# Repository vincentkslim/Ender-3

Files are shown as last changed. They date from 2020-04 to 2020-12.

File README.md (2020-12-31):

# Ender i3 Pro

This reposity contains all of the modifications I have made to my Ender 3 Pro, which I now call the
Ender i3 Pro due to the heavy design inspiration of the Prusa i3 series on my [completely redesigned x-axis carraige](#x-carriage). 
This was forked from the official Creality Ender-3 repository, which does not include files for the 
Ender 3 Pro. However, the only files that are officially open sourced are for the Ender 3. The 
differences between the Ender 3 and Ender 3 Pro aren't that great, and so most of the mechanical 
upgrades that I have made are compatible with both the Ender 3 and the Ender 3 Pro, with few exceptions.

## Mechanical upgrades

The mechanical upgrades are in the [Ender-3 Mechanical/Ender-3 Upgrades/](Ender-3%20Mechanical/Ender-3%20Upgrades)
folder. Inside that folder are a series of other folders, each containing a different upgrade. I 
designed each of these upgrades using Solidworks 2019-2020.

Here is a description of each of the folders:

### [ABL](Ender-3%20Mechanical/Ender-3%20Upgrades/ABL)

This was an experimental upgrade that tried to add auto bed leveling using the z-axis microswitch
and an allen key that was attached to the x-axis carriage. In my testing, this did not work that 
well and was not accurate enough to produce usable measurements. 

### [Direct Drive](Ender-3%20Mechanical/Ender-3%20Upgrades/Direct%20Drive)

This simply repositioned the stock extruder system to be attached to the x-axis carriage. This was a
modification of (this adapter on thingiverse)[https://www.thingiverse.com/thing:3386628] that
was modified to fit the Hero Me cooling system. 

**DO NOT USE THIS OR THE HERO ME COOLING SYSTEM, ESPECIALLY IF YOU HAVE A V6 STYLE HOTEND**. 
If you look at the model, the heatsink fan duct does not direct air to the lowest fins on the hotend
heatsink, which is where cooling is needed **the most**. In my testing, I ran into tons of heat creep
issues when I used filament seceptible to heat creep such as Prusament PLA (Prusament PLA has been
extensively documented as seceptible to heat creep).

### [E3D V6](Ender-3%20Mechanical/Ender-3%20Upgrades/E3D%20V6)

This is simply a model of the E3D V6 hotend pulled from GrabCAD [here](https://grabcad.com/library/e3d-v6-hotend-3).
When you download it from GrabCAD, the mate (in Solidworks) between the heat break and the nozzle is incorrect, so 
the length of the entire hotend from the top of the heatsink to the tip of the nozzle is shorter than
it should be. After fixing that mate, the length of the entire hotend is correct. 

### [Radial Cooling Fan 50mm DC12V](Ender-3%20Mechanical/Ender-3%20Upgrades/Radial%20Cooling%20Fan%2050mm%20DC12V)

This is just a model of a generic 5015 blower fan.

### [Rear Electronics Case](Ender-3%20Mechanical/Ender-3%20Upgrades/Rear%20Electronics%20Case)

This is a rear electronics case meant to replace the sheet metal electronics enclosure of the stock
Ender 3 and Ender 3 Pro. On the Ender 3 Pro, the electronics enclosure is opened from the bottom, 
making it absurdly annoying to change any of the wiring (for example, replacing the mainboard). 
This rear electronics case was heavily inspired by 
[Teaching Tech's rear electronics case](https://www.thingiverse.com/thing:3688967) as well, but
I designed one myself just for design practice and because I wanted to make a few modifications, 
including:

* Cable chain clips that work with [this](https://www.thingiverse.com/thing:2920060) popular printable
cable chain for the Ender 3
* Fan that points directly at the mainboard
* Cable tie mounting points
* Buck converter mounting points, which enables the Ender 3 power supply to power a Raspberry Pi.

One known issue is that the tolerances are much too tight, which makes it hard to slide in the case
at the back. Will fix in a future revision.

### [Samla Box clips](Ender-3%20Mechanical/Ender-3%20Upgrades/Samla%20Box%20clips)

These are box clips for the [IKEA SAMLA series](https://www.ikea.com/us/en/cat/samla-series-12553/)
of storage boxes. I intended to use these to make a filament drybox, but I have not gotten around to
completing that project.

### [X Carriage](Ender-3%20Mechanical/Ender-3%20Upgrades/X%20Carriage)

This is my biggest and most important upgrade. This upgrade is complete and is currently in use on
the current iteration of my Ender 3 Pro. This is a completely redesigned x-axis carriage that scraps
all the stock hot-end parts except for the metal plate and the three rollers. Features include:

* Direct Drive
* E3D V6 support
* Can use 30mm hotend cooling fan and fan duct included with the V6
* Can use a 4010 (or 4020) hotend cooling fan with a fan duct adapter
* Custom extruder with Bondtech dual drive gear support
* 5015 part cooling fan and fan duct

My design takes heavy inspiration from the Prusa i3 x-axis carriage design. 

### [Raspberry Pi 3 Model B](Ender-3%20Mechanical/Ender-3%20Upgrades/raspberry-pi-3-model-b-reference-design-solidworks-cad-rpi-raspberrypi-raspberry-pi-1.snapshot.83)

This is just a model of the Raspberry Pi 3 Model B that I use to run Octoprint and Klipper.

## Software upgrades

The software modifications I made are not included in this directory. The main change I made was 
installing [Klipper](https://www.klipper3d.org/) instead of Marlin for the firmware and having it 
run via Octoprint. I use PrusaSlicer as my slicer, although I have had good experience with Ultimaker
Cura and would recommend that as well (I used that originally).

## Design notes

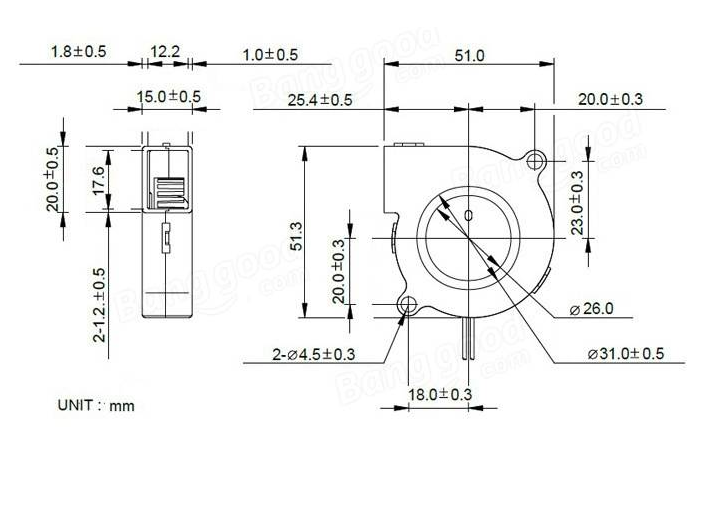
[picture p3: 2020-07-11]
Ender-3 Mechanical/Ender-3 Upgrades/Radial Cooling Fan 50mm DC12V/5015 fan.PNG

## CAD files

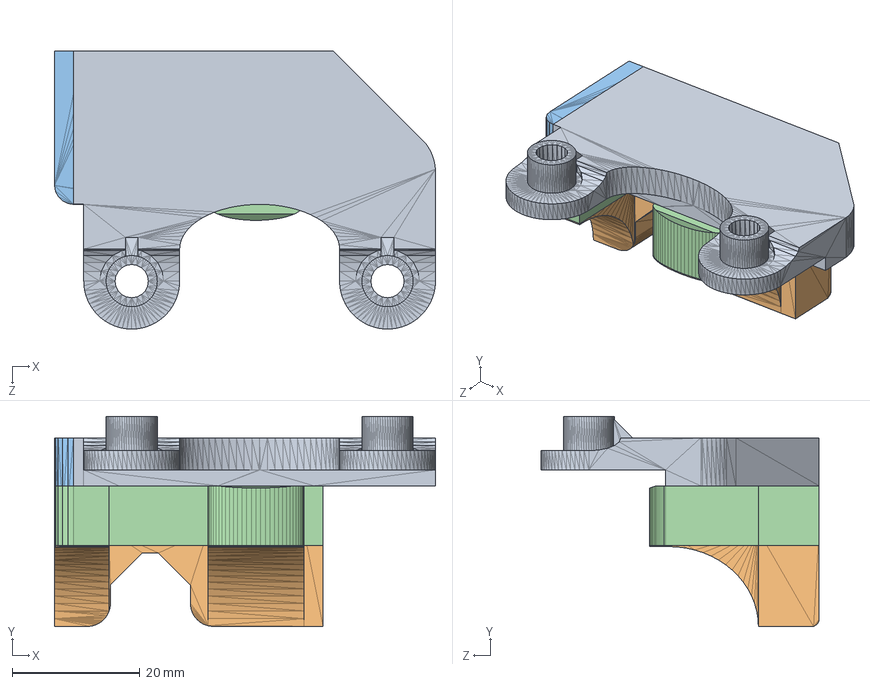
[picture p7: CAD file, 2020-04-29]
Ender-3 Mechanical/Ender-3 Upgrades/Direct Drive/_test/fits_hero_me/direct_drive_fits_e3d_v6_hero_me.SLDASM
59.6 x 32.8 x 43.5 mm

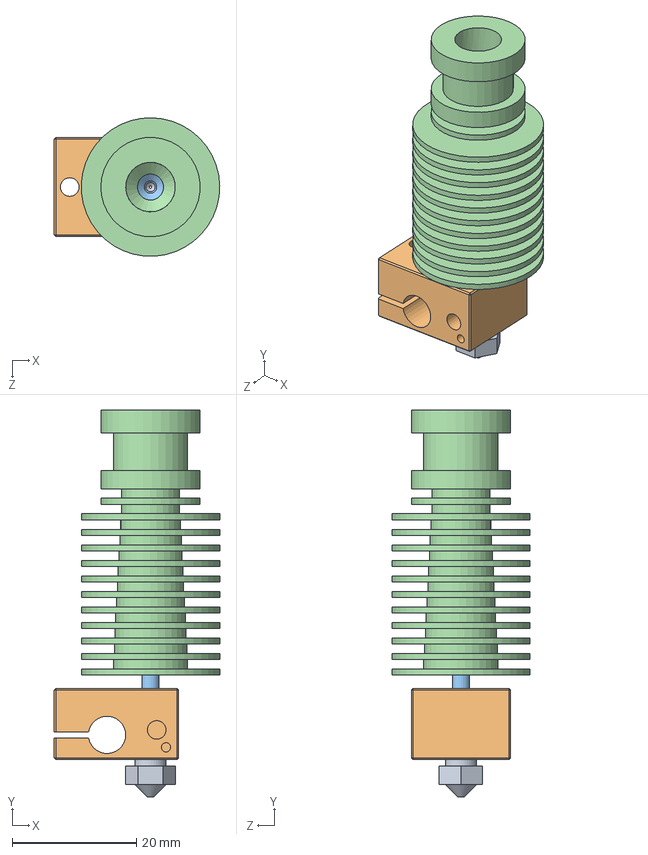
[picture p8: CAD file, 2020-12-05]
Ender-3 Mechanical/Ender-3 Upgrades/E3D V6/e3d v6.SLDASM
26.6 x 62.3 x 22.3 mm
e3d nozzle (0.4)
e3d heaterblock
e3d heat break
e3d heatsink

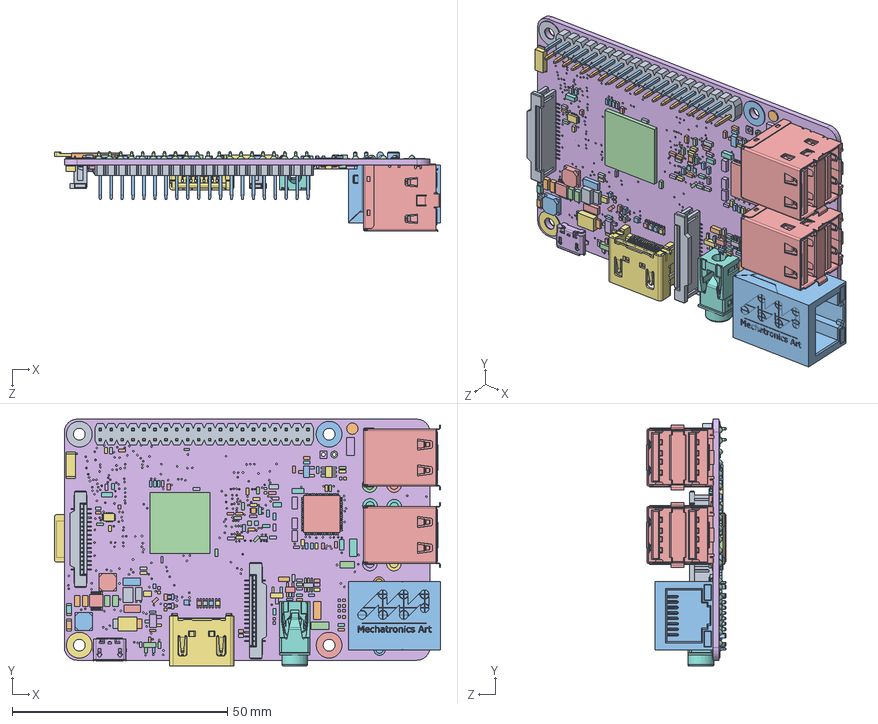
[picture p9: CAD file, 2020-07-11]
Ender-3 Mechanical/Ender-3 Upgrades/raspberry-pi-3-model-b-reference-design-solidworks-cad-rpi-raspberrypi-raspberry-pi-1.snapshot.83/Solidworks Complete Assembly/Raspberry Pi 3.SLDASM
89.6 x 57.3 x 18.6 mm
Raspberry Pi 3157
Raspberry Pi 3242 x 20
Raspberry Pi 3266 x 20
raspberry_pi_3(bar_180_2x20)
MOLEX_672983090 x 2
molex_0473460001
molex_0471510001
PJ-322
te_1-1734248-5 x 2
MOLEX_1040310811
raspberry_pi_B_(RJ45)
Raspberry Pi 312
Raspberry Pi 314
Raspberry Pi 3172
Raspberry Pi 3173
Raspberry Pi 3174
Raspberry Pi 3175
Raspberry Pi 3176
Raspberry Pi 3177
Raspberry Pi 3178
Raspberry Pi 3179
Raspberry Pi 3180
Raspberry Pi 3181
Raspberry Pi 3182
Raspberry Pi 3183
Raspberry Pi 3184
Raspberry Pi 3185
Raspberry Pi 3186
Raspberry Pi 3187
Raspberry Pi 3188
Raspberry Pi 3189
Raspberry Pi 3190
Raspberry Pi 3191
Raspberry Pi 3192
Raspberry Pi 3193
Raspberry Pi 3194
Raspberry Pi 3195
Raspberry Pi 3196
Raspberry Pi 3197
Raspberry Pi 3198
Raspberry Pi 3199
Raspberry Pi 3200
Raspberry Pi 3201
Raspberry Pi 3202
Raspberry Pi 3203
Raspberry Pi 3204
Raspberry Pi 3205
Raspberry Pi 3206
Raspberry Pi 3207
Raspberry Pi 3208
Raspberry Pi 3209
Raspberry Pi 3210
Raspberry Pi 3211
Raspberry Pi 3212
Raspberry Pi 3213
Raspberry Pi 3214
Raspberry Pi 3215
Raspberry Pi 3216
Raspberry Pi 3217
Raspberry Pi 3218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

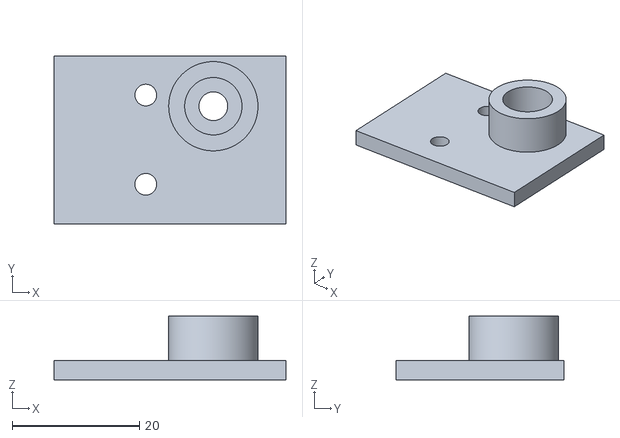
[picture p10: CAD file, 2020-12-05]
Ender-3 Mechanical/Ender-3 Upgrades/X Carriage/_stl/Part2^ASM Printing Head.STL
36.4 x 26.4 x 10.0

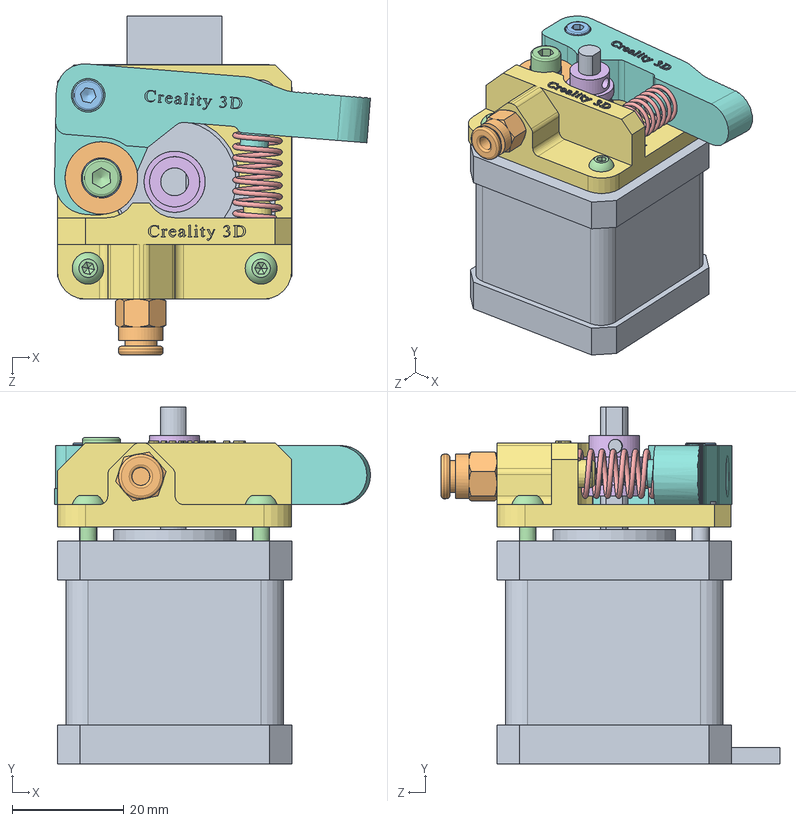
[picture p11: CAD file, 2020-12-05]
Ender-3 Mechanical/Ender-3 Parts/ASM Extruder.SLDASM
56.7 x 64.0 x 60.7 mm
40-42 motor
624U pillow
M3X18 Socket Head Screw
M3X10 Pan Head Screw x 2
Extrusion Spring
E gear
E housing 2
E idler tensioner
M3X10 Flush Head Screw
M6 Pneumatic joint
M4 Split Washer
M4X8 Socket Head Screw

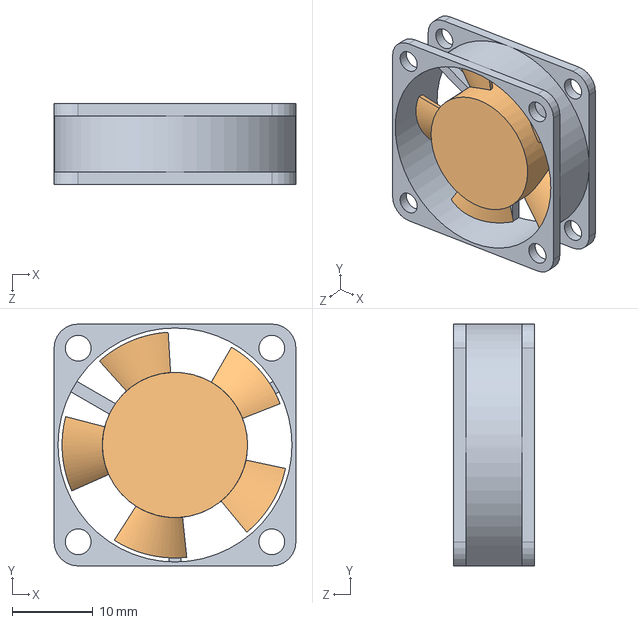
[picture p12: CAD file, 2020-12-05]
Ender-3 Mechanical/Ender-3 Upgrades/E3D V6/fan.SLDASM
30.0 x 30.0 x 10.0 mm
fan sub1
fan sub2

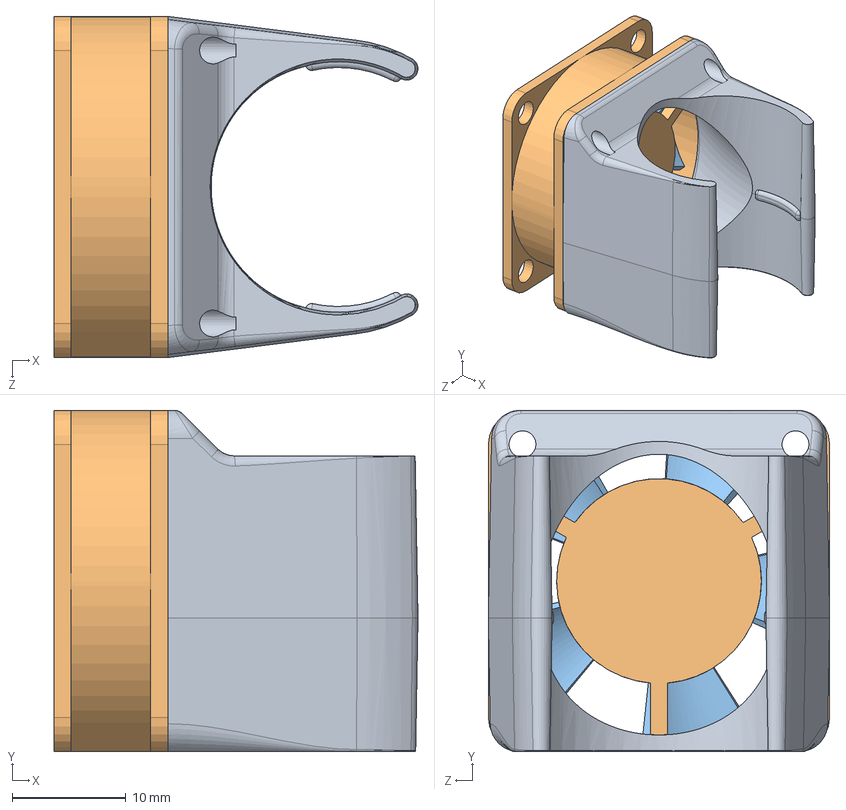
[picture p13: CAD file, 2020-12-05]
Ender-3 Mechanical/Ender-3 Upgrades/E3D V6/fanduct.SLDASM
32.0 x 30.0 x 30.0 mm
fan duct
fan sub1
fan sub2

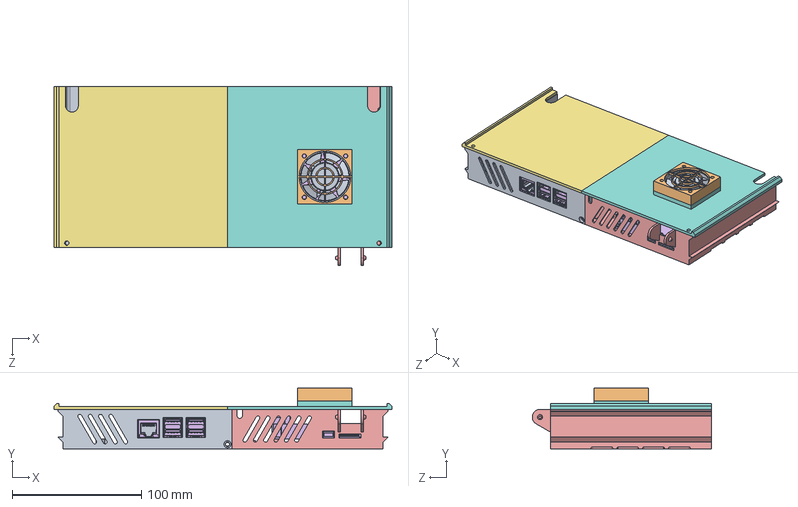
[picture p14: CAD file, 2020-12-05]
Ender-3 Mechanical/Ender-3 Upgrades/Rear Electronics Case/Rear_Electronics_Case.SLDASM
261.8 x 46.9 x 139.0 mm
case_left
Raspberry Pi 3157
Raspberry Pi 3242 x 20
Raspberry Pi 3266 x 20
raspberry_pi_3(bar_180_2x20)
MOLEX_672983090 x 2
molex_0473460001
molex_0471510001
HANRUN2_HR911105A
PJ-322
te_1-1734248-5 x 2
MOLEX_1040310811
raspberry_pi_3(RJ45)
raspberry_pi_B_(RJ45)
Raspberry Pi 312
Raspberry Pi 314
Raspberry Pi 3172
Raspberry Pi 3173
Raspberry Pi 3174
Raspberry Pi 3175
Raspberry Pi 3176
Raspberry Pi 3177
Raspberry Pi 3178
Raspberry Pi 3179
Raspberry Pi 3180
Raspberry Pi 3181
Raspberry Pi 3182
Raspberry Pi 3183
Raspberry Pi 3184
Raspberry Pi 3185
Raspberry Pi 3186
Raspberry Pi 3187
Raspberry Pi 3188
Raspberry Pi 3189
Raspberry Pi 3190
Raspberry Pi 3191
Raspberry Pi 3192
Raspberry Pi 3193
Raspberry Pi 3194
Raspberry Pi 3195
Raspberry Pi 3196
Raspberry Pi 3197
Raspberry Pi 3198
Raspberry Pi 3199
Raspberry Pi 3200
Raspberry Pi 3201
Raspberry Pi 3202
Raspberry Pi 3203
Raspberry Pi 3204
Raspberry Pi 3205
Raspberry Pi 3206
Raspberry Pi 3207
Raspberry Pi 3208
Raspberry Pi 3209
Raspberry Pi 3210
Raspberry Pi 3211
Raspberry Pi 3212
Raspberry Pi 3213
Raspberry Pi 3214
Raspberry Pi 3215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

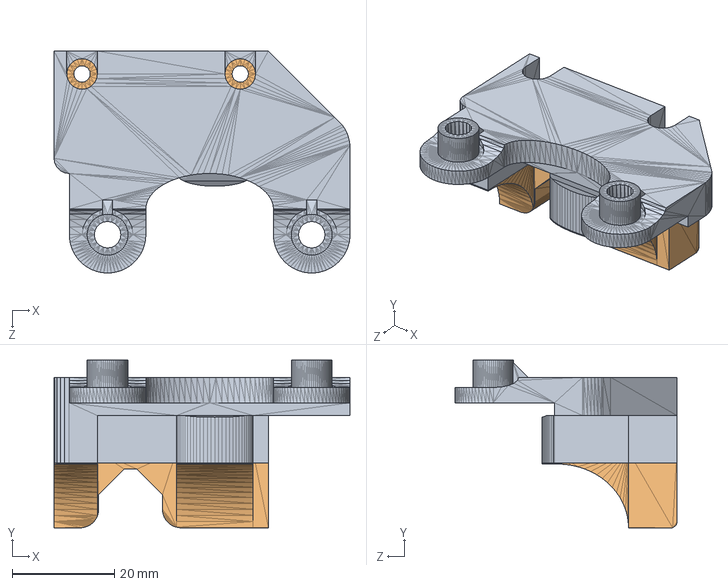
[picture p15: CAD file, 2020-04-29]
Ender-3 Mechanical/Ender-3 Upgrades/Direct Drive/_test/assembly.SLDASM
58.0 x 32.8 x 43.5 mm

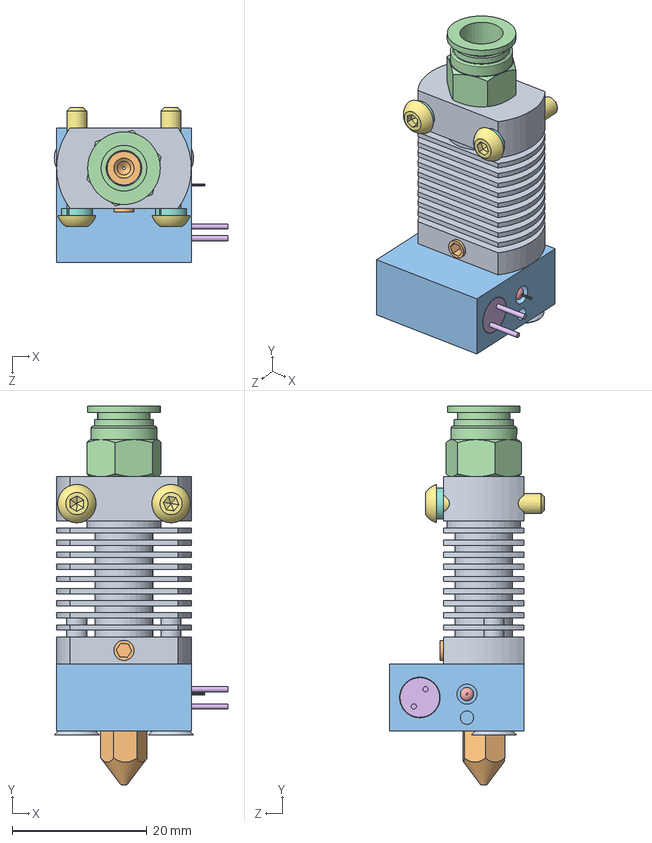
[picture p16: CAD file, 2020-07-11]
Ender-3 Mechanical/Ender-3 Parts/ASM Heating Unit.SLDASM
25.8 x 56.3 x 23.0 mm
Radiator
nozzle
Heat block
Pneumatic joint
Nozzle thermistor
Heater
M3X16 Pan Head Screw x 2
M3 Split Washer x 2
M3×18 Flush Head Screw x 2
M3 Screw x 2

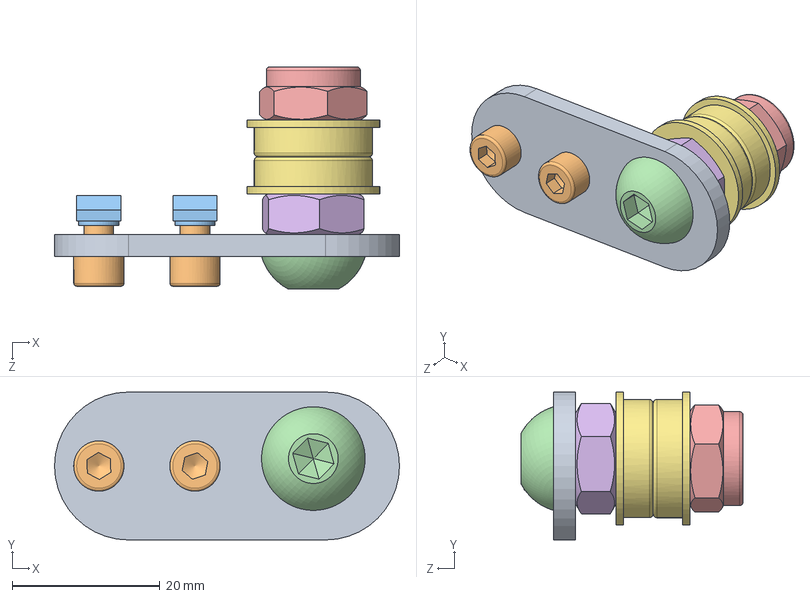
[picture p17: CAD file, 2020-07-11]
Ender-3 Mechanical/Ender-3 Parts/ASM X-Belt Tensioner.SLDASM
46.7 x 20.0 x 30.1 mm
X Adjustment Block
M4X8 Socket Head Screw x 2
M5 T-Slot Nut x 2
M8X25 Pan Head Screw
M8 Self-locking nut
M8 nut
F688 pillow x 2

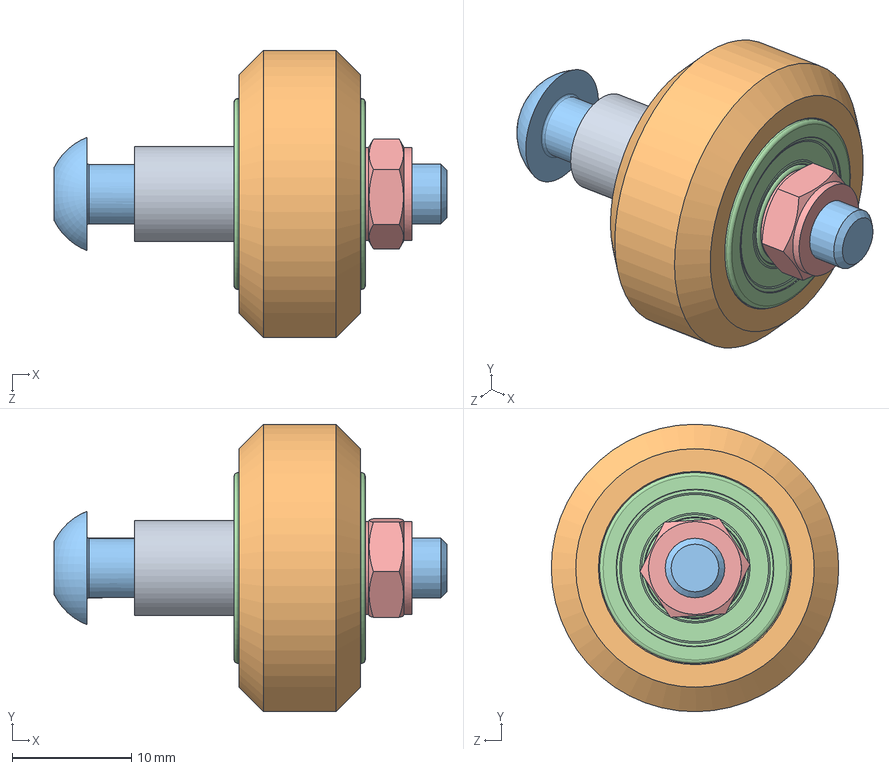
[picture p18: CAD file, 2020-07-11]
Ender-3 Mechanical/Ender-3 Parts/ASM Roller X-Axis.SLDASM
33.0 x 24.1 x 24.1 mm
Spacers for rollers
Rollers
M5X30 Pan Head Screw
625pillow x 2
M5 Self-locking nut

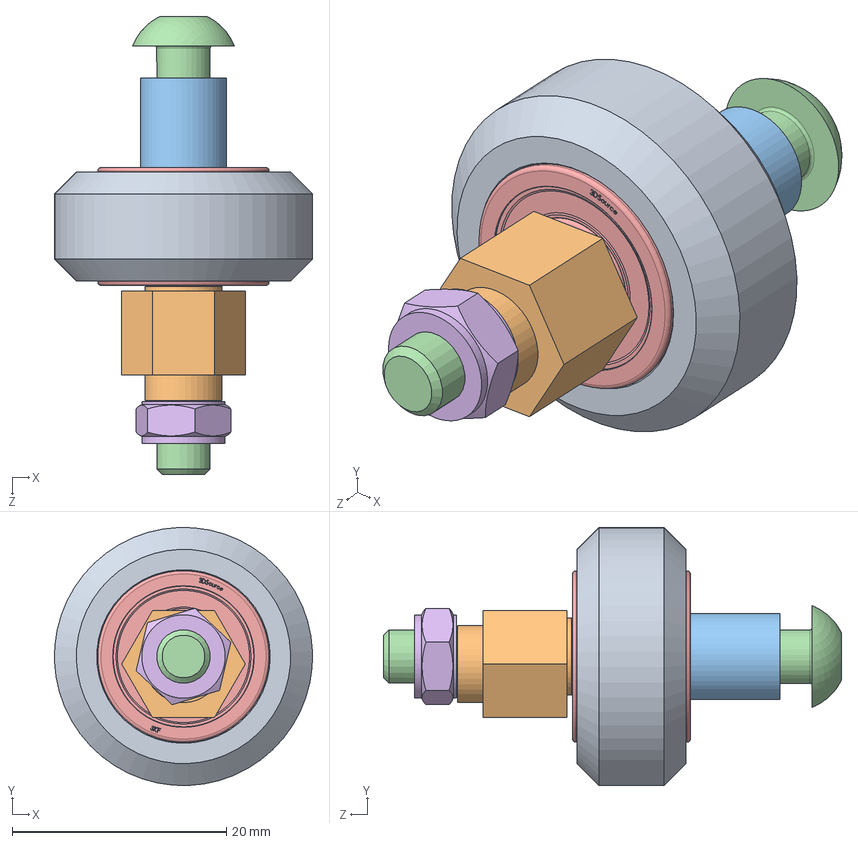
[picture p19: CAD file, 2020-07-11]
Ender-3 Mechanical/Ender-3 Parts/ASM Eccentrical Roller Z-Axis Left.SLDASM
24.1 x 24.1 x 42.8 mm
Rollers
Eccentric column
Spacers for rollers
M5X40 Pan Head Screw
625pillow x 2
M5 Self-locking nut

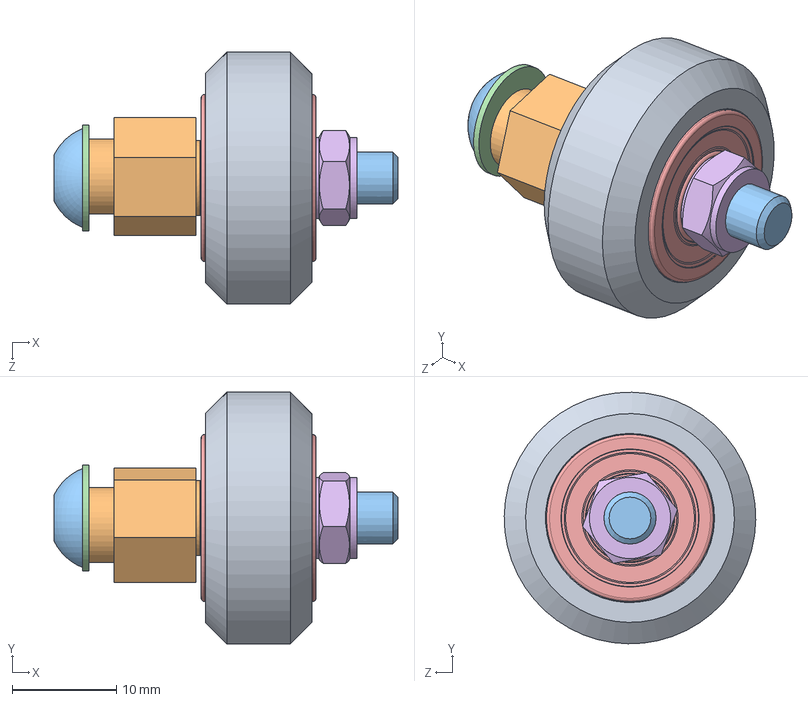
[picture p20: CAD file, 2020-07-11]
Ender-3 Mechanical/Ender-3 Parts/ASM Eccentrical Roller X-Axis.SLDASM
33.0 x 24.1 x 24.1 mm
Rollers
Eccentric column
M5X30 Pan Head Screw
M5 washer
625pillow x 2
M5 Self-locking nut

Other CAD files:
Ender-3 Mechanical/Ender-3 Parts/ASM Roller Z-Axis Right.SLDASM
Ender-3 Mechanical/Ender-3 Parts/ASM Roller Z-Axis Left.SLDASM
Ender-3 Mechanical/Ender-3 Parts/ASM Bed.SLDASM
Ender-3 Mechanical/Ender-3 Parts/ASM Eccentrical Roller Z-Axis Right.SLDASM
Ender-3 Mechanical/Ender-3 Parts/2020 Endcap.SLDPRT
Ender-3 Mechanical/Ender-3 Parts/2020 profile.SLDPRT
Ender-3 Mechanical/Ender-3 Parts/2020-2 profile.SLDPRT
Ender-3 Mechanical/Ender-3 Parts/2040-2 profile.SLDPRT
Ender-3 Mechanical/Ender-3 Parts/2040-3L profile.SLDPRT
Ender-3 Mechanical/Ender-3 Parts/2040-3R profile.SLDPRT
Ender-3 Mechanical/Ender-3 Parts/24V15A power supply.SLDPRT
Ender-3 Mechanical/Ender-3 Parts/2GT-pulley.SLDPRT
Ender-3 Mechanical/Ender-3 Parts/40-42 motor.SLDPRT
Ender-3 Mechanical/Ender-3 Parts/4040 profile.SLDPRT
Ender-3 Mechanical/Ender-3 Parts/4040-3 profile.SLDPRT
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

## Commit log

2020-04-09 Added rear electonics enclosure
    [2020 Endcap.SLDPRT, 2040-2 profile.SLDPRT, 40-42 motor.SLDPRT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]
2020-04-29 direct drive, rear electronics case
    [1.5mm allen key test 2.1.STL, 1.5mm allen key test 2.2.STL, 1.5mm allen key test.SLDPRT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]
2020-07-11 fan duct and idler door
    [001.SLDPRT, 002.SLDPRT, 002_mirrored.SLDPRT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]
2020-12-05 more upgrades
    [001.SLDPRT, 001.STL, 001_with_weatherseal.STL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]
